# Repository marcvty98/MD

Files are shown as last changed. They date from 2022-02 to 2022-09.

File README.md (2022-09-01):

# Foreword.
We recommend downloading the Technical Manual, to know in depth all the variables, software process installation, mechanical devices, communication protocols, electrical connections, CAD/CAM designs. And, in (possible) Furthcoming situations, you will do maintenance work and make improvements.   

# MD
Well... you and I just wanna know how this thing works, or what doesn´t work (yet :smile: ) in the shortest time .... 

## [src](https://github.com/marcvty98/MD/tree/main/src)
1. Here you can find two directories:
  - [mobile_robot_navigation](https://github.com/marcvty98/MD/tree/main/src/mobile_robot_autonomous_navigation)
  - [ydlidar_ros_driver](https://github.com/marcvty98/MD/tree/main/src/ydlidar_ros_driver)
 
2. These needs to be moved in your ROS workspace (copy or cut). 

3. Compile your ROS workspace
```
ctrl+alt+t
cd "your_ROS_workspace"
catkin_make
```

### [mobile_robot_autonomous_navigation](https://github.com/marcvty98/MD/tree/main/src/mobile_robot_autonomous_navigation)

#### [arduino_code](https://github.com/marcvty98/MD/tree/main/src/mobile_robot_autonomous_navigation/arduino_code)
Here there are only two directories with one file each one, the arduino code for each control wheel. Both codes are same, i2c direction is the unique difference between. 

#### [config](https://github.com/marcvty98/MD/tree/main/src/mobile_robot_autonomous_navigation/config)
The specific ROS configurations to do SLAM:
  - local and global map settings
  - velocity, acceleration and jerk limits
  - joint limits
  - mapping configurations
  - path planning
  - rviz profiles
 
 Are here.

#### [launch](https://github.com/marcvty98/MD/tree/main/src/mobile_robot_autonomous_navigation/launch) 
To do SLAM ROS tasks:
  - Checking the URDF file
  - Cheking ans testing robot's controllers
  - Mapping settings
  - Autonomous navigations settings

#### [maps](https://github.com/marcvty98/MD/tree/main/src/mobile_robot_autonomous_navigation/maps)
After explorations task, all maps will be saved there. 

#### [scripts](https://github.com/marcvty98/MD/tree/main/src/mobile_robot_autonomous_navigation/scripts)
Personal Python scripts for navigation can be created, like:
  - Sequential goals
  - Petitions by terminal to arrive somewhre
  - etc

#### [stl](https://github.com/marcvty98/MD/tree/main/src/mobile_robot_autonomous_navigation/stl)
Personal designs, crated in CAD/CAM tools, like:
  - robot cases
  - wheels
  - sesnors cases
  - robotic arms (or his parts)
  - mechanisms (like exoskeletons)
  -etc

These will be here with a .stl or .STL extention. 

#### [urdf](https://github.com/marcvty98/MD/tree/main/src/mobile_robot_autonomous_navigation/urdf)
Robot setup can be constructed with one or some files with .urdf extension.

### ydlidar_ros_driver
To use a Lidar with ros, you need ROS settings too. Well, everything about how lidar sensor works are here.

The current project is completely configured and no necessary do changes in this directory. But, if you want to know more about the YDLIDAR (X4 sensor), you can see his GitHub repository [here](https://github.com/YDLIDAR/ydlidar_ros).

## [3D Printing stl files](https://github.com/marcvty98/MD/tree/main/3D%20Printing%20stl%20files)
You will see the following directories and files within: 
  - Carcasa para KY040
    - box.STL
    - tapa.STL
  - Engranajes
    - engrj.STL
    - pinon.STL
  - Nivelador
    - eje.STL
  - Ranura
    - ranura2.STL
 
 These files are ready to be printed. 

## [Design](https://github.com/marcvty98/MD/tree/main/Design)
The project design was divided in two parts:
1. Diseño para el Sistema de Locomoción: Every part for the robot can do moves (rotations and rotations).
2. Diseño para el Sistema de Conteo: Every part part for the robot can do Odometry.

## [Electrical Diagrams](https://github.com/marcvty98/MD/tree/main/electrical%20diagrams)
Finally, all informations about the , electronic devices and partials and 
  - Electrical connections
    - Real GPIO's
    - Wires (and specific colors needed)
  - Electronic devices
    - Microcontrollers
    - Motors
    - H Bridge
    - Batteries
    - Encoder Sensors
  - Voltage Regulators
 
 And, the diagrams were made with Fritzing, reason why there's a directory called "Parts", if you want to change something.

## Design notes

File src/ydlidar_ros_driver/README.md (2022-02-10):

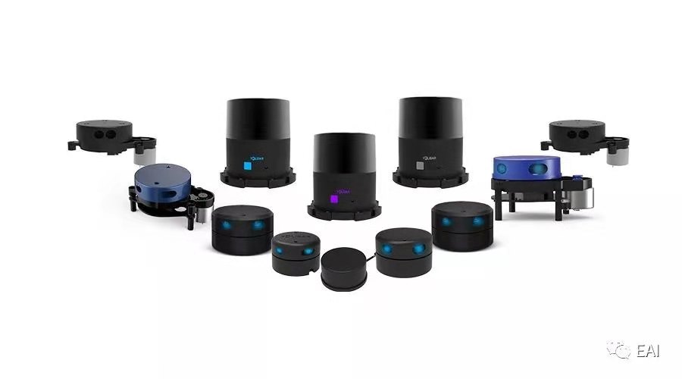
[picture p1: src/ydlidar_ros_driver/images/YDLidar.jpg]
YDLIDAR

# YDLIDAR ROS Driver

ydlidar_ros_driver is a new ros package, which is designed to gradually become the standard driver package for ydlidar devices in the ros environment.

## Compile & Install YDLidar SDK

ydlidar_ros_driver depends on YDLidar-SDK library. If you have never installed YDLidar-SDK library or it is out of date, you must first install YDLidar-SDK library. If you have installed the latest version of YDLidar-SDK, skip this step and go to the next step.

1. Download or clone the [YDLIDAR/YDLidar-SDK](https://github.com/YDLIDAR/YDLidar-SDK) repository on GitHub.
2. Compile and install the YDLidar-SDK under the ***build*** directory following `README.md` of YDLIDAR/YDLidar-SDK.

## Clone ydlidar_ros_driver

1. Clone ydlidar_ros_driver package for github : 

   `git clone https://github.com/YDLIDAR/ydlidar_ros_driver.git ydlidar_ws/src/ydlidar_ros_driver`

2. Build ydlidar_ros_driver package :

   ```
   cd ydlidar_ws
   catkin_make
   ```
   <font color=Red size=4>>Note: If the following error occurs, Please install  [YDLIDAR/YDLidar-SDK](https://github.com/YDLIDAR/YDLidar-SDK) first.</font>

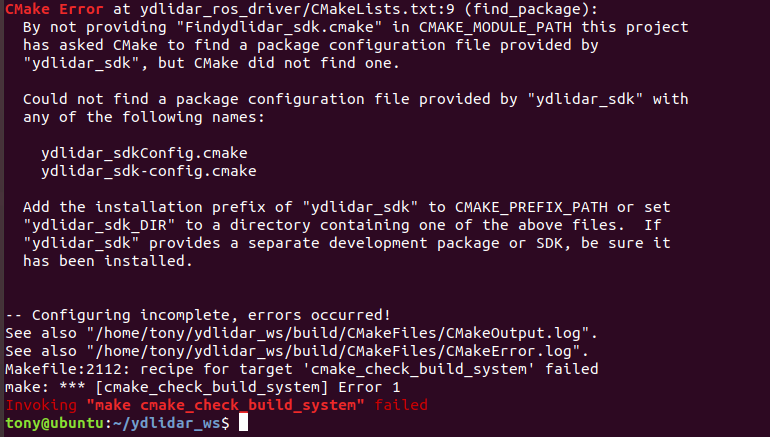
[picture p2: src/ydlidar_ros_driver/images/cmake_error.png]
CMAKE ERROR
   

3. Package environment setup :

   `source ./devel/setup.sh`

    Note: Add permanent workspace environment variables.
    It's convenientif the ROS environment variables are automatically added to your bash session every time a new shell is launched:
    ```
    $echo "source ~/ydlidar_ws/devel/setup.bash" >> ~/.bashrc
    $source ~/.bashrc
    ```
4. Confirmation
    To confirm that your package path has been set, echo the `ROS_PACKAGE_PATH` variable.
    ```
    $ echo $ROS_PACKAGE_PATH
    ```
    You should see something similar to:
        `/home/tony/ydlidar_ws/src:/opt/ros/melodic/share`

5. Create serial port Alias [optional] 
    ```
	$chmod 0777 src/ydlidar_ros_driver/startup/*
	$sudo sh src/ydlidar_ros_driver/startup/initenv.sh
    ```
    Note: After completing the previous operation, replug the LiDAR again.

## Run ydlidar_ros_driver

##### Run ydlidar_ros_driver using launch file

The command format is : 

 `roslaunch ydlidar_ros_driver [launch file]`

1. Connect Triangle LiDAR uint(s).
   ```
   # G4, G5
   roslaunch ydlidar_ros_driver lidar_view.launch 
   ```

2. Connect to TOF LiDAR uint(s).
   ```
   # TG15, TG30, TG50
   roslaunch ydlidar_ros_driver TG.launch 
   # TX8, TX20
   roslaunch ydlidar_ros_driver TX.launch 
   ```
3. Connect to TOF NET LiDAR uint(s).
   ```
   # T5, T15
   roslaunch ydlidar_ros_driver T15.launch 
   ```

#####  Launch file introduction

The driver offers users a wealth of options when using different launch file. The launch file directory    

is `"ydlidar_ws/src/ydlidar_ros_driver/launch"`. All launch files are listed as below : 

| launch file | features |
| --- | --- |
| G1.launch | Connect to G1 LiDAR<br/>Publish LaserScan message on `scan` topic |
| G2.launch | Connect to G2 LiDAＲ<br/>Publish LaserScan message on `scan` topic |
| G6_G7.launch | Connect to G6/G7 LiDAR<br />Publish LaserScan message on `scan` topic |
| lidar.launch | Connect to G4/G5 LiDAR<br />Publish LaserScan message on `scan` topic |
| lidar_view.launch | Connect to G4/G5 LiDAR<br />Publish LaserScan message on `scan` topic <br/>Automatically load rviz |
| T15.launch | Connect to T5/T15 LiDAR<br />Publish LaserScan message on `scan` topic |
| TG.launch | Connect to TG15/TG30/TG50 LiDAR<br />Publish LaserScan message on `scan` topic |
| TX.launch | Connect to TX8/TX20 LiDAR<br />Publish LaserScan message on `scan` topic |
| X2.launch | Connect to X2/X2L LiDAR<br />Publish LaserScan message on `scan` topic |
| X4.launch | Connect to X4 LiDAR<br />Publish LaserScan message on `scan` topic |

## Publish Topic
| Topic | Type | Description |
|---|---|---|
| `scan` | sensor_msgs/LaserScan | 2D laser scan of the 0-angle ring  
| `point_cloud` | sensor_msgs/PointCloud  | 2D point cloud of the 0-angle ring |
| ~~`laser_fan`~~(removed in version 1.0.1) | ydlidar_ros_driver::LaserFan | 2D Raw laser fan of the 0-angle ring |

## Subscribe Service
| Service | Type | Description |
|---|---|---|
| `stop_scan` | std_srvs::Empty | turn off lidar |
| `start_scan` | std_srvs::Empty | turn on lidar |

## Configure ydlidar_ros_driver internal parameter

The ydlidar_ros_driver internal parameters are in the launch file, they are listed as below :

| Parameter name | Data Type | detail |
| --- | --- | --- |
| port | string | Set Lidar the serial port or IP address <br/>it can be set to `/dev/ttyUSB0`, `192.168.1.11`, etc. <br/>default: `/dev/ydlidar` |
| frame_id | string | Lidar TF coordinate system name. <br/>default: `laser_frame` |
| ignore_array | string | LiDAR filtering angle area<br/>eg: `-90, -80, 30, 40` |
| baudrate | int | Lidar baudrate or network port. <br/>default: `230400` |
| lidar_type | int | Set lidar type <br/>0 -- TYPE_TOF<br/>1 -- TYPE_TRIANGLE<br/>2 -- TYPE_TOF_NET <br/>default: `1` |
| device_type | int | Set device type <br/>0 -- YDLIDAR_TYPE_SERIAL<br/>1 -- YDLIDAR_TYPE_TCP<br/>2 -- YDLIDAR_TYPE_UDP <br/>default: `0` |
| sample_rate | int | Set Lidar Sample Rate. <br/>default: `9` |
| abnormal_check_count | int | Set the number of abnormal startup data attempts. <br/>default: `4` |
| fixed_resolution | bool | Fixed angluar resolution. <br/>default: `true` |
| reversion | bool | Reversion LiDAR. <br/>default: `true` |
| inverted | bool | Inverted LiDAR.<br/>false -- ClockWise.<br/>true -- CounterClockWise  <br/>default: `true` |
| auto_reconnect | bool | Automatically reconnect the LiDAR.<br/>true -- hot plug. <br/>default: `true` |
| isSingleChannel | bool | Whether LiDAR is a single-channel.<br/>default: `false` |
| intensity | bool | Whether LiDAR has intensity.<br/>true -- G2 LiDAR.<br/>default: `false` |
| support_motor_dtr | bool | Whether the Lidar can be started and stopped by Serial DTR.<br/>default: `false` |
| angle_min | float | Minimum Valid Angle.<br/>default: `-180` |
| angle_max | float | Maximum Valid Angle.<br/>default: `180` |
| range_min | float | Minimum Valid range.<br/>default: `0.1` |
| range_max | float | Maximum Valid range.<br/>default: `16.0` |
| frequency | float | Set Scanning Frequency.<br/>default: `10.0` |
| invalid_range_is_inf | bool | Invalid Range is inf.<br/>true -- inf.<br/>false -- 0.0.<br/>default: `false` |
| point_cloud_preservative  | bool | Keep invalid range.<br/>true -- Keep.<br/>false -- Reject.<br/>default: `false` |
More paramters details, see [here](details.md)

## Contact EAI
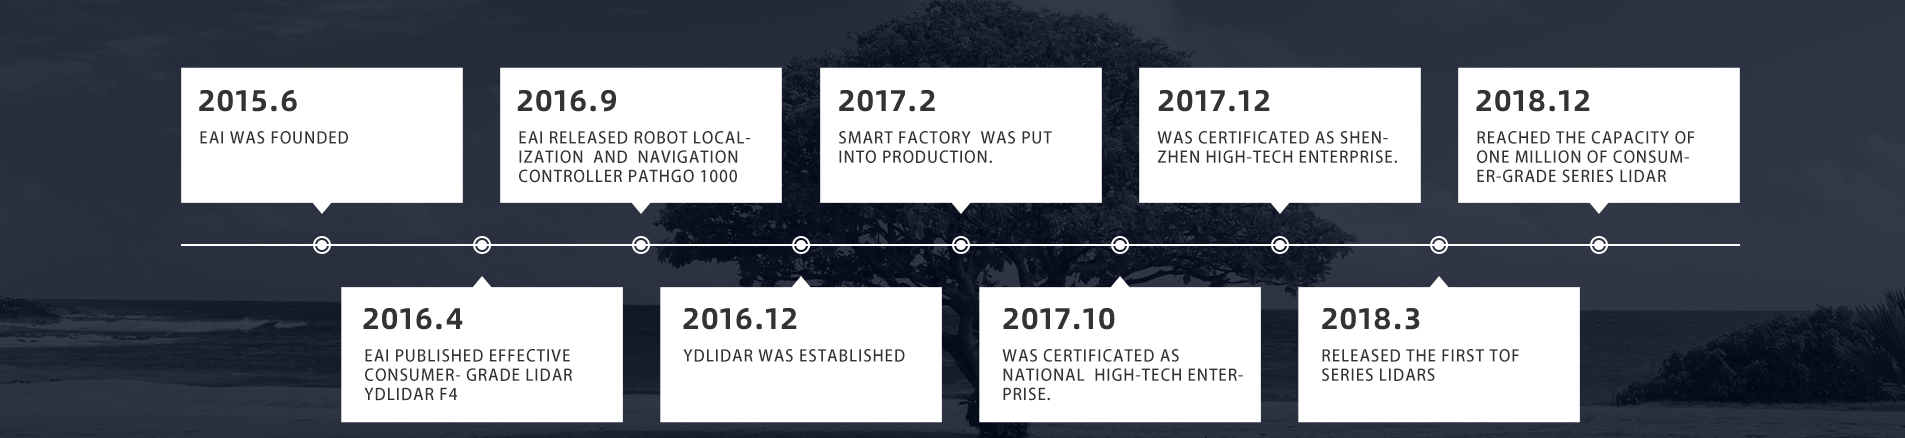
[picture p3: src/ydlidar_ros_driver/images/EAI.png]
Development Path


If you have any extra questions, please feel free to [contact us](http://www.ydlidar.cn/cn/contact)

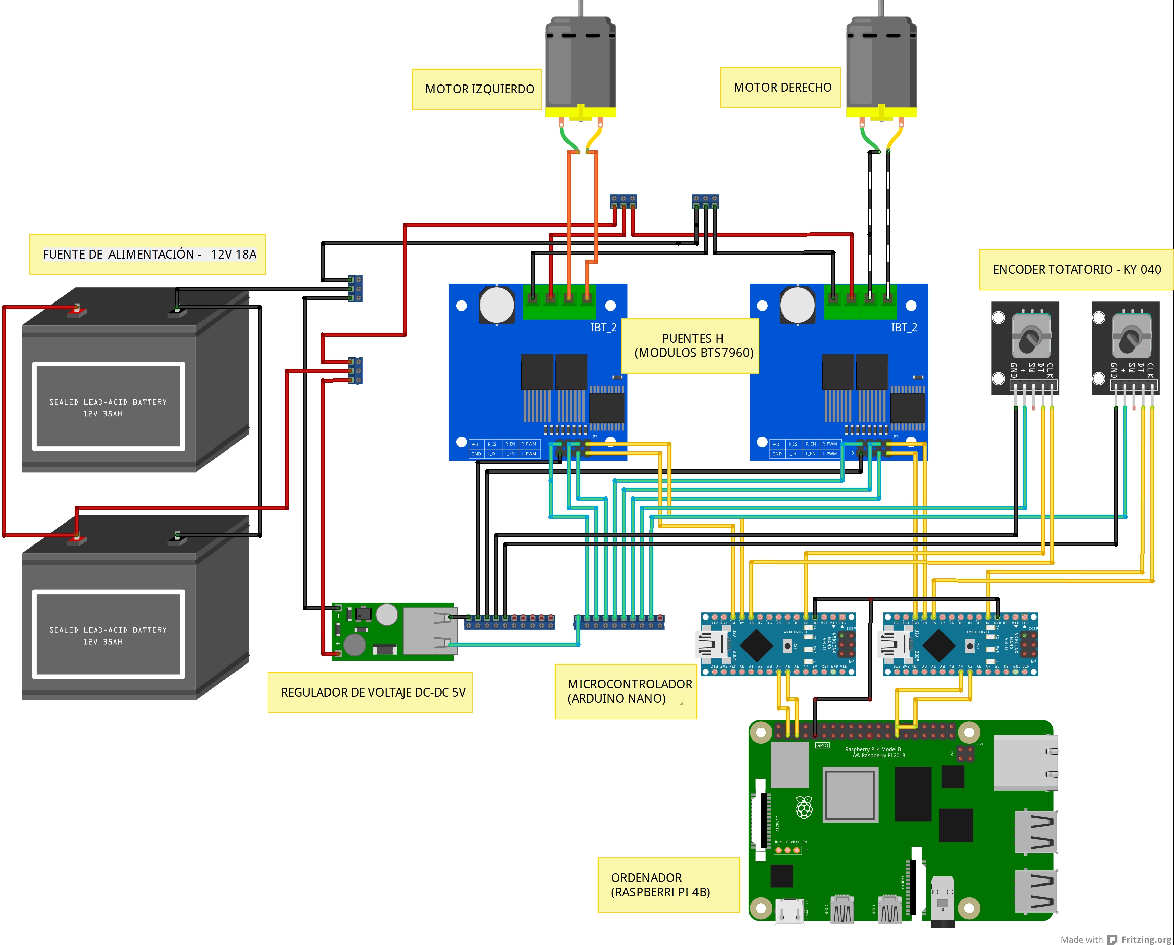
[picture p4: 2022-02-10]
electrical diagrams/Diagram/elec_dia_com.jpg

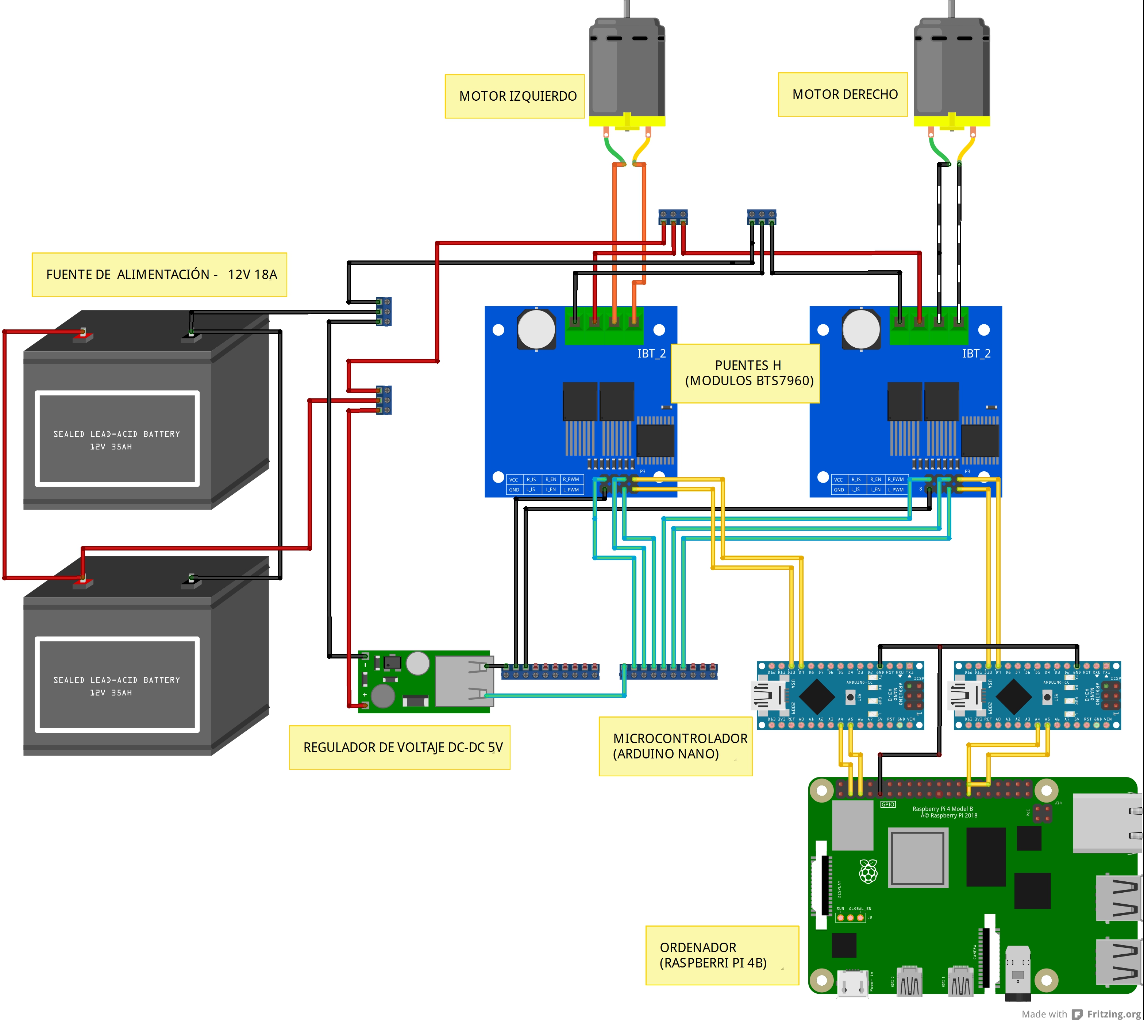
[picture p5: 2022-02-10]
electrical diagrams/Diagram/sis_loc.jpg

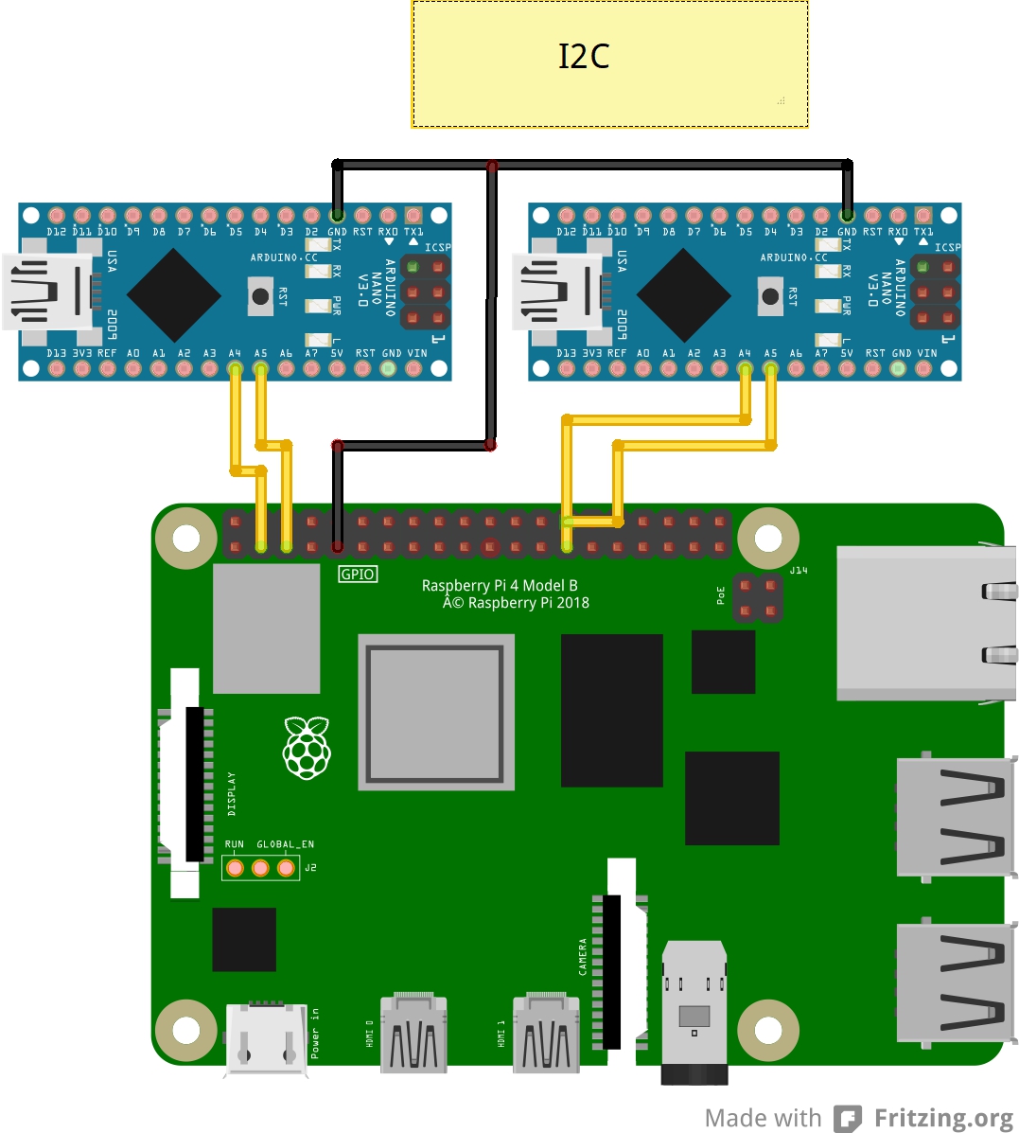
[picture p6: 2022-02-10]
electrical diagrams/Diagram/i2c.jpg

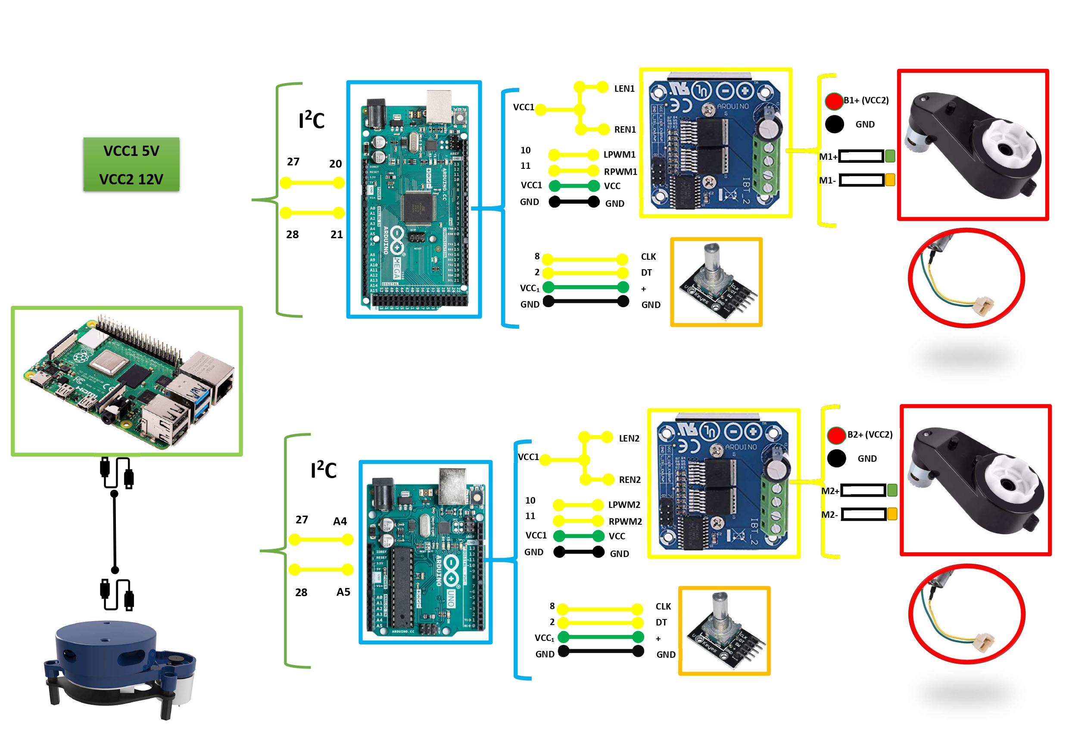
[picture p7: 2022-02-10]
electrical diagrams/Diagram/digel.jpg

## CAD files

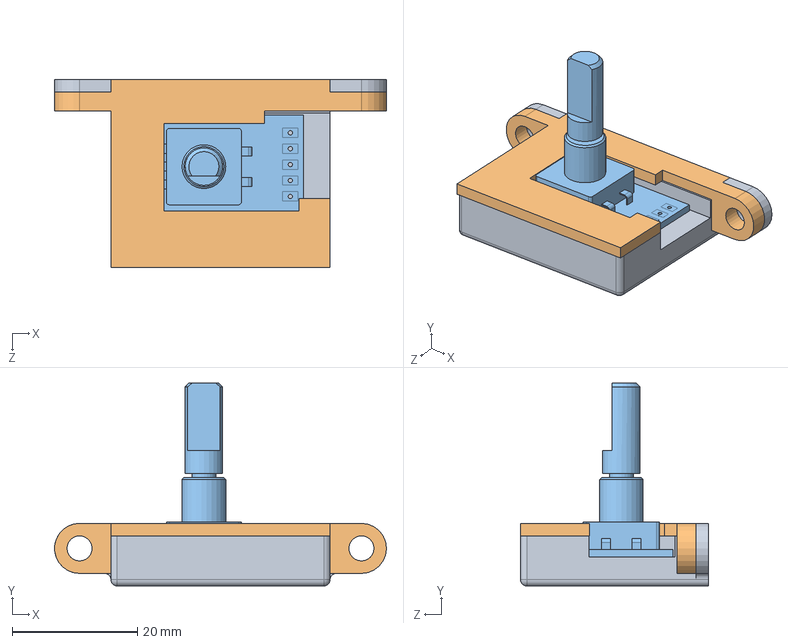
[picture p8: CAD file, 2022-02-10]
Designs/Diseño para el Sistema de conteo/Carcasa para KY040/ensa_enc.SLDASM
53.0 x 32.4 x 30.0 mm
tapa
Encoder KY-040

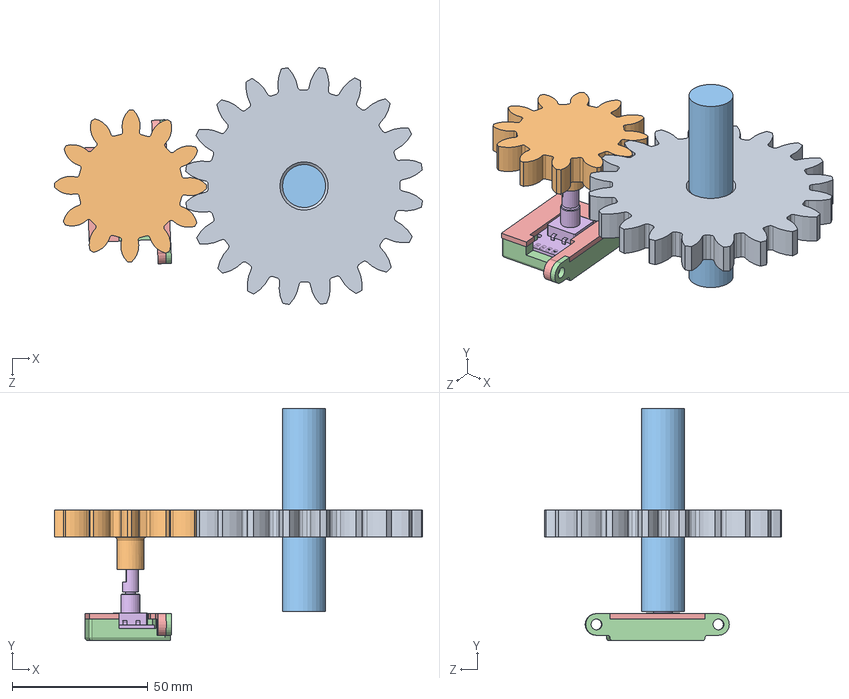
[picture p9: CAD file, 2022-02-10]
Designs/Diseño para el Sistema de conteo/Engranajes/Engranajes ensamble/ensa_engr.SLDASM
135.7 x 85.7 x 87.3 mm
engrj
pinon
tubo
tapa
Encoder KY-040

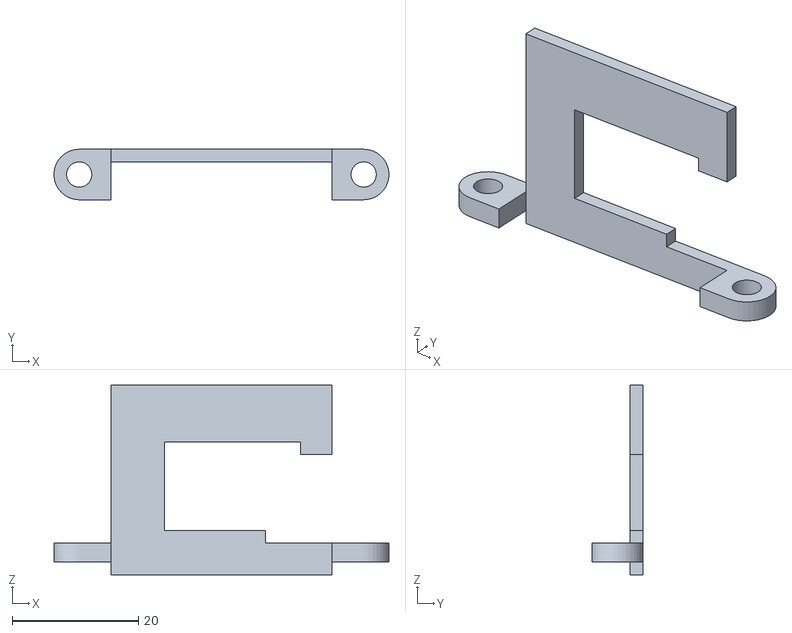
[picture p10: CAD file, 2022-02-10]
3D Printing stl file/Carcasa para KY040/tapa.STL
53.0 x 8.00 x 30.0

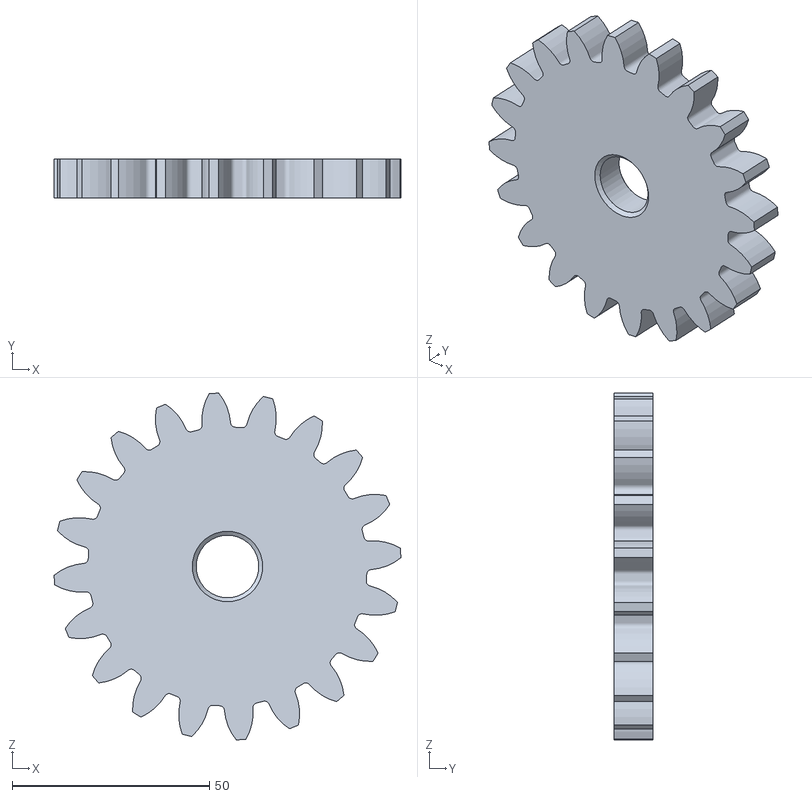
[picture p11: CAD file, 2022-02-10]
3D Printing stl file/Engranajes/engrj.STL
87.9 x 10.0 x 87.9

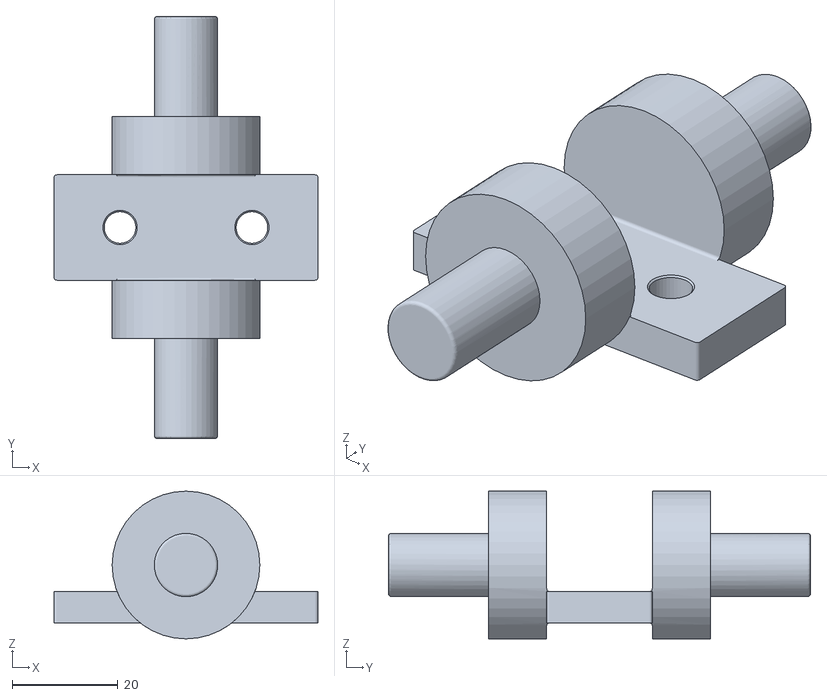
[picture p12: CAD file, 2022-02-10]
3D Printing stl file/Nivelador/eje.STL
50.0 x 80.0 x 28.0

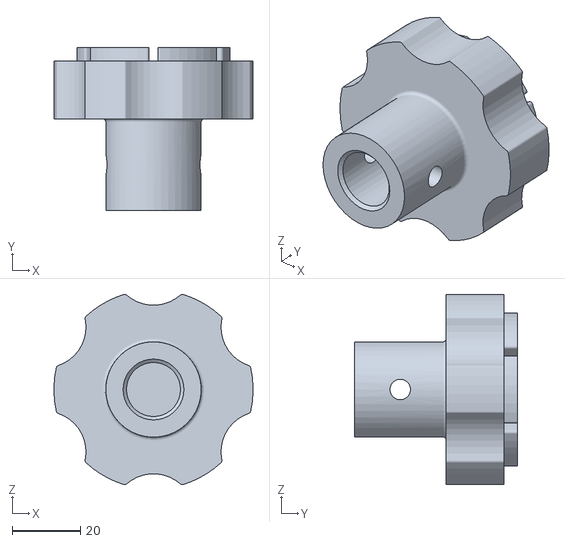
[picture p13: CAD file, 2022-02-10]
3D Printing stl file/Ranura/ranura2.STL
58.4 x 48.0 x 55.9

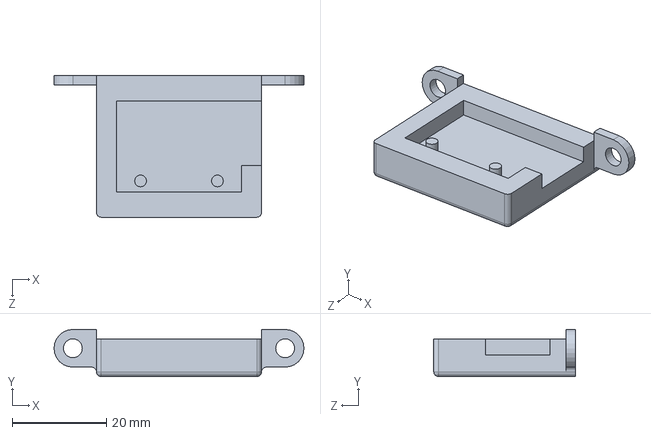
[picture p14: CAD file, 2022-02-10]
Designs/Diseño para el Sistema de conteo/Carcasa para KY040/box/box.SLDPRT
53.0 x 10.0 x 30.0 mm

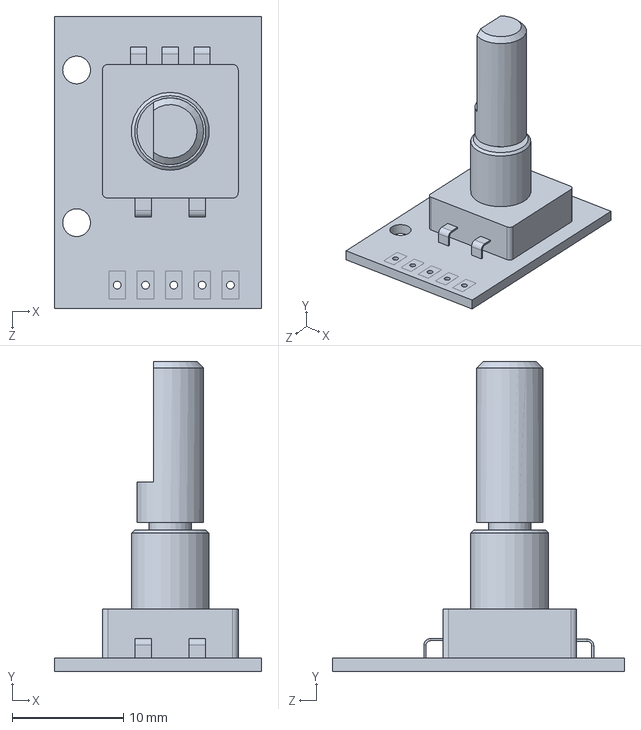
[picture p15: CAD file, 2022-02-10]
Designs/Diseño para el Sistema de conteo/Carcasa para KY040/snr_enc/Encoder KY-040.SLDPRT
18.6 x 27.8 x 26.2 mm

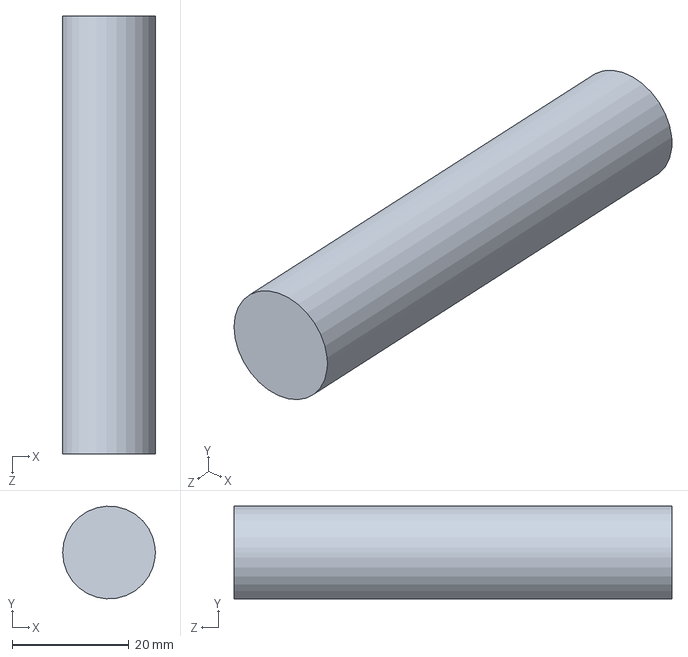
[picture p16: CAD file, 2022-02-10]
Designs/Diseño para el Sistema de conteo/Engranajes/Engranajes ensamble/tubo.SLDPRT
15.9 x 15.9 x 75.0 mm

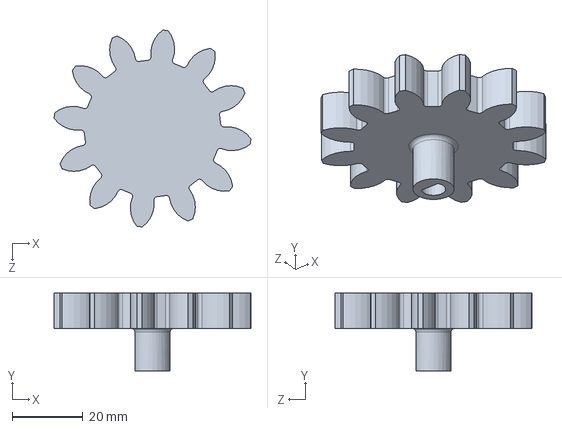
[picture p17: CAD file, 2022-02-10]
Designs/Diseño para el Sistema de conteo/Engranajes/Pinon/pinon.SLDPRT
55.7 x 22.0 x 55.7 mm

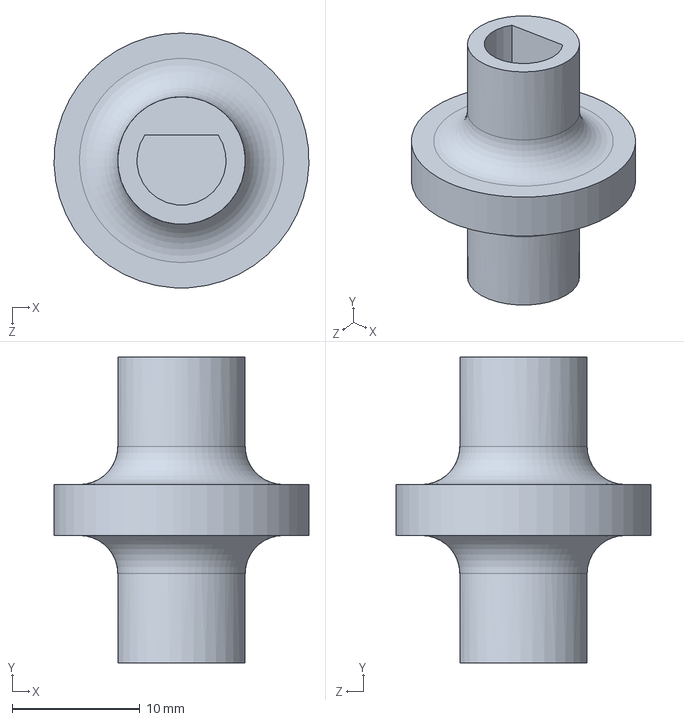
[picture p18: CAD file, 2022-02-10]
Designs/Diseño para el Sistema de conteo/tst_snsrs/prb_01.SLDPRT
20.0 x 24.0 x 20.0 mm

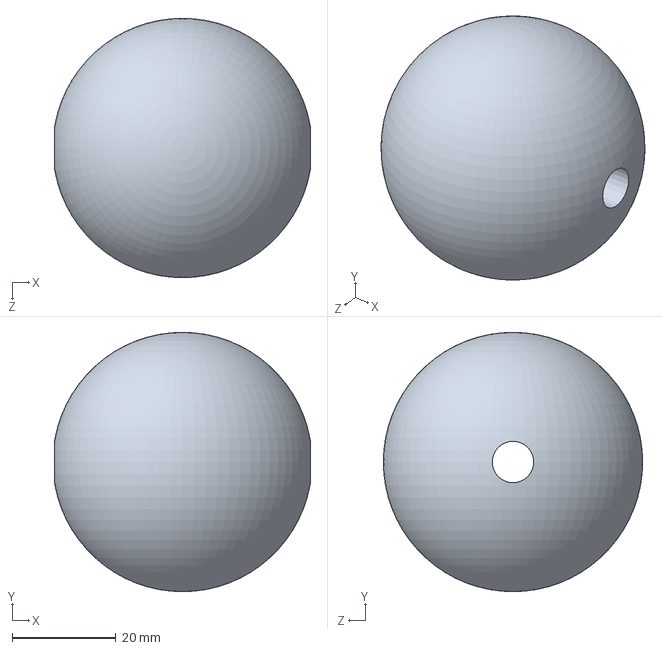
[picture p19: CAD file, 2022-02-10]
Designs/Diseños para el Sistema de Locomocion/castor/cstr.SLDPRT
49.4 x 50.0 x 50.0 mm

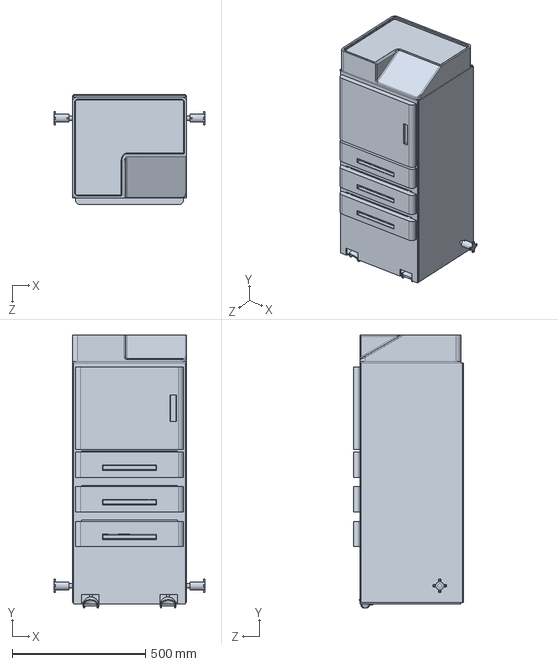
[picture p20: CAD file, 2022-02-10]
Designs/Diseños para el Sistema de Locomocion/chassis/chassis.SLDPRT
566.0 x 1025.5 x 415.0 mm

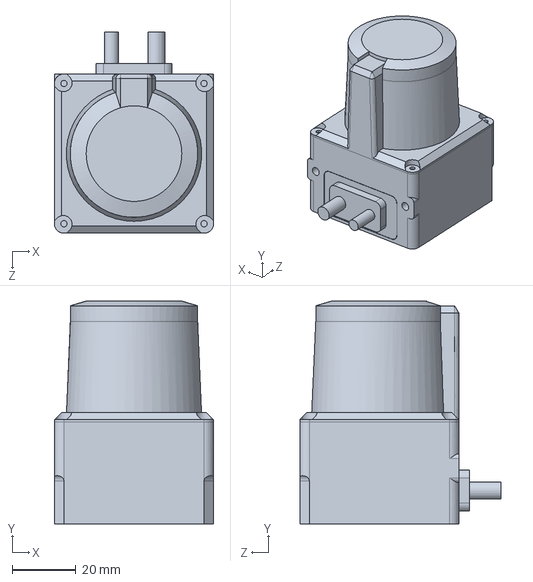
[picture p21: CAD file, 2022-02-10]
Designs/Diseños para el Sistema de Locomocion/LiDAR/hokuyo-ust10lx.SLDPRT
50.0 x 70.0 x 63.2 mm

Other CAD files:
Designs/Diseño para el Sistema de conteo/Carcasa para KY040/tapa/tapa.SLDPRT
Designs/Diseño para el Sistema de conteo/Engranajes/Engrane/engrj.SLDPRT
Designs/Diseño para el Sistema de conteo/Nivelador/eje.SLDPRT
Designs/Diseño para el Sistema de conteo/Ranura/ranura2.SLDPRT
3D Printing stl file/Carcasa para KY040/box.STL
3D Printing stl file/Engranajes/pinon.STL
Designs/Diseño para el Sistema de conteo/Carcasa para KY040/box/box.STL
Designs/Diseño para el Sistema de conteo/Engranajes/Pinon/pinon.STL
Designs/Diseño para el Sistema de conteo/Ranura/ranura.SLDPRT
Designs/Diseño para el Sistema de conteo/tst_snsrs/prb_01.STL
Designs/Diseños para el Sistema de Locomocion/LiDAR/hky.STL
Designs/Diseños para el Sistema de Locomocion/castor/cstr.STL
Designs/Diseños para el Sistema de Locomocion/chassis/chassis.STL
Designs/Diseños para el Sistema de Locomocion/wheel/wheel.SLDPRT
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

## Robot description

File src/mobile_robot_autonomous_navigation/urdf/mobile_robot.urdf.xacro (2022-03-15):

<?xml version="1.0"?>
<robot name="mobile_robot" xmlns:xacro="http://ros.org/wiki/xacro">

    <material name="blue">
	    <color rgba="0 0 0.8 1"/>
    </material>

    <material name="white">
	    < color rgba="1 1 1 1" />
    </material>

    <material name="black">
	    <color rgba="0 0 0 1"/>
    </material>

    <material name="green">
        <color rgba="0.0 0.8 0.0 1.0"/>
    </material>

    <link name="base_link">
        <!--<visual>
          <geometry>
             <box size="0.24 0.24 0.001"/>
          </geometry>
          <material name="white"/>
          <origin rpy="0 0 0" xyz="0 0 0.0005"/>
          <material>
            <color rgba="0 0 0.8 1" />
          </material>
        </visual> -->
        <collision>
          <origin rpy="0 0 0" xyz="0 0 0"/>
          <geometry>
            <box size="0.22 0.22 0.001"/>
          </geometry>
        </collision>
    </link>

    <joint name="base_link_joint" type="fixed">
        <origin xyz="0 0 0" rpy="0 0 0" />
        <parent link="base_link" />
        <child link="base_plate" />
    </joint>

    <link name="base_plate">
    <visual>
      <origin rpy="1.5708 0 1.5708" xyz="-0.42 -0.3 0.02"/>
      <geometry>
        <mesh filename="package://mobile_robot_autonomous_navigation/stl/chassis.STL" scale="0.001 0.001 0.001"/> 
      </geometry>
      <material name="white"/>
    </visual>
    <collision>
      <origin rpy="1.5708 0 1.5708" xyz="-0.42 -0.3 0.02" />
      <geometry>
        <mesh filename="package://mobile_robot_autonomous_navigation/stl/chassis.STL" scale="0.001 0.001 0.001" />
      </geometry>
    </collision>
    </link>   
    
    
    <joint name="right_wheel_joint" type="continuous">
        <origin xyz="-0.1 -0.27 0.1" rpy="0 0 0" />
        <parent link="base_plate" />
        <child link="right_wheel" />
        <axis xyz="0 -1 0" />
    </joint>

    <link name="right_wheel">
    <visual>
      <origin rpy="1.5708 0 0" xyz="-0.1 0.025 -0.1"/>
      <geometry>
        <mesh filename="package://mobile_robot_autonomous_navigation/stl/wheel.STL" scale="0.001 0.001 0.001"/> 
      </geometry>
      <material name="black"/>
    </visual>
    <collision>
      <origin rpy="1.5708 0 0" xyz="-0.1 0.025 -0.1"/>
      <geometry>
        <mesh filename="package://mobile_robot_autonomous_navigation/stl/wheel.STL" scale="0.001 0.001 0.001" />
      </geometry>
    </collision>
    </link>   
    
    <joint name="left_wheel_joint" type="continuous">
        <origin xyz="-0.1 0.24 0.1" rpy="0 0 0" />
        <parent link="base_plate" />
        <child link="left_wheel" />
        <axis xyz="0 -1 0" />
    </joint>

    <link name="left_wheel">
    <visual>
      <origin rpy="1.5708 0 0" xyz="-0.1 0.025 -0.1"/>
      <geometry>
        <mesh filename="package://mobile_robot_autonomous_navigation/stl/wheel.STL" scale="0.001 0.001 0.001"/> 
      </geometry>
      <material name="black"/>
    </visual>
    <collision>
      <origin rpy="1.5708 0 0" xyz="-0.1 0.025 -0.1"/>
      <geometry>
        <mesh filename="package://mobile_robot_autonomous_navigation/stl/wheel.STL" scale="0.001 0.001 0.001" />
      </geometry>
    </collision>
    </link>   
    
    <joint name="laser_joint" type="fixed">
        <origin xyz="0 0 1.05" rpy="0 0 0" />
        <parent link="base_plate" />
        <child link="laser" />
    </joint>

    <link name="laser">
    <visual>
      <origin rpy="0 0 -1.5708" xyz="0.1 -0.24 -0.05"/>
      <geometry>
        <mesh filename="package://mobile_robot_autonomous_navigation/stl/RpLidar.stl" scale="0.001 0.001 0.001"/> 
      </geometry>
      <material name="blue"/>
    </visual>
    <collision>
      <origin rpy="0 0 0" xyz="0.1 -0.24 -0.05" />
      <geometry>
        <mesh filename="package://mobile_robot_autonomous_navigation/stl/RpLidar.stl" scale="0.001 0.001 0.001" />
      </geometry>
    </collision>
    </link>  

    <joint name="rigth_wheel_csr_joint" type="fixed">
        <origin xyz="0.18 -0.170 0.025" rpy="0 0 0" />
        <parent link="base_plate" />
        <child link="rigth_wheel_csr" />
    </joint>

    <link name="rigth_wheel_csr">
    <visual>
      <origin rpy="0 0 1.5708" xyz="0.02 -0.02 -0.02"/>
      <geometry>
        <mesh filename="package://mobile_robot_autonomous_navigation/stl/cstr.STL" scale="0.001 0.001 0.001"/> 
      </geometry>
      <material name="blue"/>
    </visual>
    <collision>
      <origin rpy="0 0 1.5708" xyz="0.02 -0.02 -0.02" />
      <geometry>
        <mesh filename="package://mobile_robot_autonomous_navigation/stl/cstr.STL" scale="0.001 0.001 0.001" />
      </geometry>
    </collision>
    </link>  

    <joint name="left_wheel_csr_joint" type="fixed">
        <origin xyz="0.18 0.125 0.025" rpy="0 0 0" />
        <parent link="base_plate" />
        <child link="left_wheel_csr" />
    </joint>

    <link name="left_wheel_csr">
    <visual>
      <origin rpy="0 0 1.5708" xyz="0.02 -0.02 -0.02"/>
      <geometry>
        <mesh filename="package://mobile_robot_autonomous_navigation/stl/cstr.STL" scale="0.001 0.001 0.001"/> 
      </geometry>
      <material name="blue"/>
    </visual>
    <collision>
      <origin rpy="0 0 1.5708" xyz="0.02 -0.02 -0.02" />
      <geometry>
        <mesh filename="package://mobile_robot_autonomous_navigation/stl/cstr.STL" scale="0.001 0.001 0.001" />
      </geometry>
    </collision>
    </link>  

</robot>

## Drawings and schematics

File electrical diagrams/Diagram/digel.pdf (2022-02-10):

# C I²C

## VCC1 5V

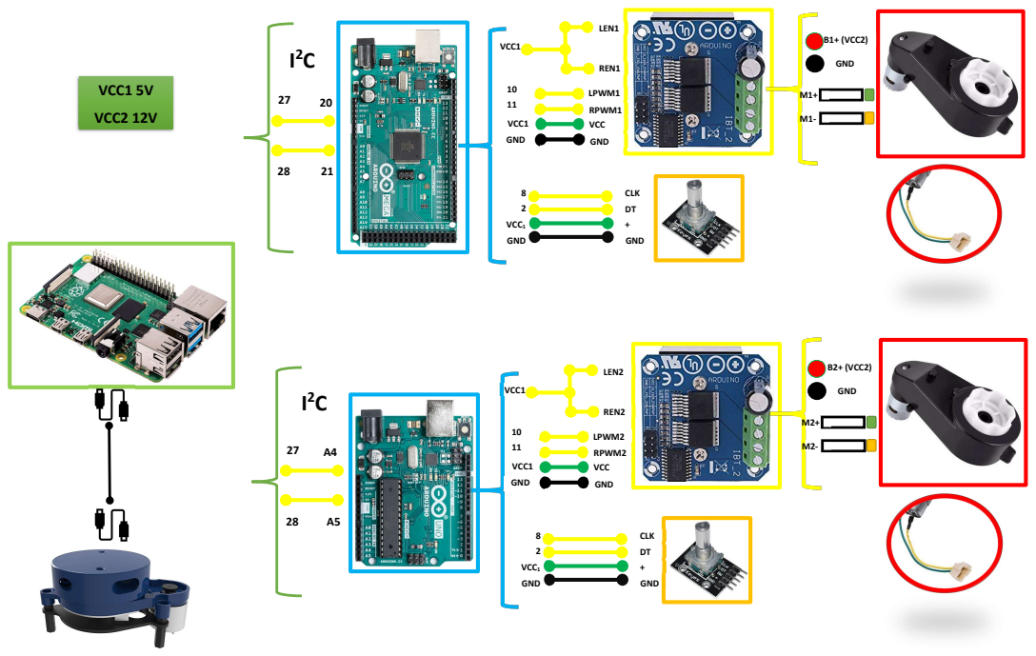
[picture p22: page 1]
CLK DT +; GND 82; VCC1 GND; VCC1; LEN1; REN1; LPWM1 RPWM1; GND; VCC; LEN2; REN2; LPWM2 RPWM2; B1+ (VCC2); B2+ (VCC2); VCC2 12V

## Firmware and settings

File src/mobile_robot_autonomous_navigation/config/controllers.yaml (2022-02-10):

mobile_robot:

    joints_update:
      type: joint_state_controller/JointStateController
      publish_rate: 50

    mobile_base_controller:
      type        : "diff_drive_controller/DiffDriveController"
      left_wheel  : 'left_wheel_joint'
      right_wheel : 'right_wheel_joint'
      publish_rate: 50.0               # default: 50
      pose_covariance_diagonal : [0.001, 0.001, 1000000.0, 1000000.0, 1000000.0, 1000.0]
      twist_covariance_diagonal: [0.001, 0.001, 1000000.0, 1000000.0, 1000000.0, 1000.0]

      # Wheel separation and diameter. These are both optional.
      # diff_drive_controller will attempt to read either one or both from the
      # URDF if not specified as a parameter
      wheel_separation : 0.5
      wheel_radius : 0.1

      # Wheel separation and radius multipliers
      wheel_separation_multiplier: 1.0 # default: 1.0
      wheel_radius_multiplier    : 1.0 # default: 1.0

      # Velocity commands timeout [s], default 0.5
      cmd_vel_timeout: 0.25

      # Base frame_id
      base_frame_id: "base_link"

      # Velocity and acceleration limits
      # Whenever a min_* is unspecified, default to -max_*
      linear:
        x:
          has_velocity_limits    : true
          max_velocity           : 0.10  # m/s
          min_velocity           : -0.10 # m/s
          has_acceleration_limits: true
          max_acceleration       : 0.025  # m/s^2
          min_acceleration       : -0.025 # m/s^2
          has_jerk_limits        : false
          max_jerk               : 2.0  # m/s^3
      angular:
        z:
          has_velocity_limits    : true
          max_velocity           : 1.0472  # rad/s
          has_acceleration_limits: true
          max_acceleration       : 0.5  # rad/s^2
          has_jerk_limits        : true
          max_jerk               : 1 # rad/s^3

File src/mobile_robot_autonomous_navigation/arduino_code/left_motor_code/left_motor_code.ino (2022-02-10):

#include <PinChangeInt.h>
#include <Wire.h>
#include <PID_v1.h>
#define encodPinA1      2                       // Quadrature encoder A pin
#define encodPinB1      8                       // Quadrature encoder B pin
#define M1              9                       // PWM outputs to L298N H-Bridge motor driver module
#define M2              10

double kp =1, ki =20 , kd =0;             // modify for optimal performance
double input = 0, output = 0, setpoint = 0;
unsigned long lastTime,now;
volatile long encoderPos = 0,last_pos=0,lastpos=0;
PID myPID(&input, &output, &setpoint, kp, ki, kd,DIRECT);  
void setup() {
  pinMode(encodPinA1, INPUT_PULLUP);                  // quadrature encoder input A
  pinMode(encodPinB1, INPUT_PULLUP);                  // quadrature encoder input B
  attachInterrupt(0, encoder, FALLING);               // update encoder position
  TCCR1B = TCCR1B & 0b11111000 | 1;                   // To prevent Motor Noise
  
  myPID.SetMode(AUTOMATIC);
  myPID.SetSampleTime(1);
  myPID.SetOutputLimits(-63, 63);
  
  Wire.begin(8);                // join i2c bus with address #8 for Right Motor
  Wire.onRequest(requestEvent); // register events
  Wire.onReceive(receiveEvent);
  //Serial.begin (9600); 
  
}

void loop() {
   now = millis();
   int timeChange = (now - lastTime);
   if(timeChange>=500 )
   {
      input = (360.0*1000*(encoderPos-last_pos)) /(25.0*(now - lastTime));
      lastTime=now;
      last_pos=encoderPos;
   }
  
  myPID.Compute();                                    // calculate new output
  pwmOut(output);                                     // drive L298N H-Bridge module
  delay(10);
}

void pwmOut(int out) {                                // to H-Bridge board
  if (out > 0) {
    analogWrite(M1, out);                             // drive motor CW
    analogWrite(M2, 0);
  }
  else {
    analogWrite(M1, 0);
    analogWrite(M2, abs(out));                        // drive motor CCW
  }
}

void encoder()  {                                     // pulse and direction, direct port reading to save cycles  
  if (PINB & 0b00000001)    encoderPos--;             // if(digitalRead(encodPinB1)==HIGH)   count --;
  else                      encoderPos++;             // if(digitalRead(encodPinB1)==LOW)   count ++;
}

void requestEvent() {
  int8_t s;
  
  s= (360.0*(encoderPos-lastpos))/25.0; //change in position in degrees of the wheel
  lastpos=encoderPos;
  Wire.write(s); // respond with message of 6 bytes
}


// function that executes whenever data is received from master
// this function is registered as an event, see setup()
void receiveEvent(int howMany)
{
  uint8_t a,b;
  a = Wire.read();
  b = Wire.read();
  setpoint= (double)((b<<8)|a);
  //Serial.println((uint8_t)a);
  //Serial.println((uint8_t)b);
  
  //Serial.println(setpoint);
}

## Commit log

2022-02-10 Prueba de publicación
    [Encoder KY-040.SLDPRT, RpLidar.stl, box.SLDPRT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]
2022-02-10 Coreeción de publicación de prueba
    [controllers.yaml]
2022-02-13 MD version 3
    [elec_dia.fzz]
2022-03-15 Quinta Actualización
    [Encoder KY-040.SLDPRT, box.SLDPRT, box.STL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]
